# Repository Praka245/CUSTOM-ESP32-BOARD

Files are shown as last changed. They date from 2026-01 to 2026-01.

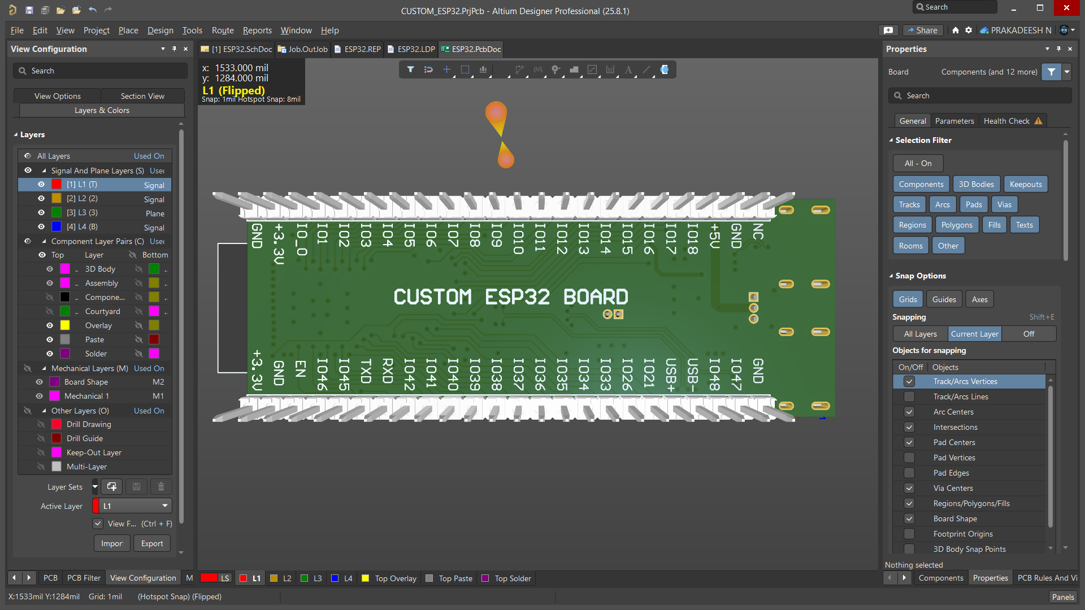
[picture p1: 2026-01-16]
IMAGES/3D VIEW/BOTTOM View.png

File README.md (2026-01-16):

# ESP32 Custom PCB Design

## 📌 Project Overview

This repository contains the complete design files for a **custom ESP32-based PCB**.  
The project focuses on schematic design, component selection, PCB layout, and manufacturing outputs such as Gerber and NC Drill files.

The design follows standard PCB design practices and is intended for **learning, prototyping, and academic purposes**.

---

## 🛠 Tools Used
Altium   

- **PCB Design Software:** Altium Designer
- **Gerber Viewer:** View Mate

---

## 🛠 Key Component and Files

- **Controller:** ESP32  
- **Output Files:** Gerber, NC Drill, BOM  
- **3D Models:** STEP (.stp)

---

## 🔍 Websites used to search Components

The following online resources were used to **search, verify, and download PCB components, footprints, symbols, and 3D models**:

1. **Digi-Key**  
2. **LCSC**
3. **Molex**  
4. **SnapEDA / SnapEDA Magic**
5. **Ultra Librarian** 
6. **3D ContentCentral**

**Note:** For 3D visualization and mechanical verification, **STEP (.stp) files** were downloaded and used.

---

## 📂 Manufacturing Output Files

This repository includes the following fabrication-ready files:

- **Gerber Files** - Copper layers, solder mask, silkscreen  
- **NC Drill Files (.DRR)** - Drill data for vias and holes  
- **Drill Reports (.TXT)** - Hole size and count information  

---

## 👁 Viewing Gerber & NC Drill Files (Optional)

To view and verify Gerber files before fabrication, the following tool was used:

### ViewMate Gerber Viewer

- Open and inspect Gerber layers  
- Verify drill alignment and hole sizes  
- Check PCB before sending to fabrication  

**LINK:** https://www.pentalogix.com/t/software-products/viewmate

---

## 🎯 Project Objectives

- Learn complete PCB design flow  
- Understand component selection and footprint verification  
- Generate fabrication-ready files  
- Practice industry-standard PCB documentation  

---

## 📐 Controlled Impedance Routing (50 Ω)

In this PCB design, **50 Ω characteristic impedance** was maintained for moderate-speed digital signal routing.

### Design Choice

- **Trace Width:** 6 mils  
- **Target Impedance:** 50 Ω  
- **Signal Type:** moderate-speed digital signals  
- **Routing Style:** Single-ended microstrip

The 6 mil trace width was selected based on the **PCB stack-up parameters**, including:
- Dielectric material (FR-4)
- Dielectric thickness between signal layer and reference plane
- Copper thickness
- Presence of a continuous ground reference plane

Using these parameters, impedance calculations confirmed that a **6 mil wide trace achieves approximately 50 Ω** characteristic impedance under the given stack-up conditions.

---

### Why 50 Ω?

- Industry-standard impedance for:
  - High-speed digital signals
  - RF and clock lines
- Minimizes:
  - Signal reflections
  - Impedance mismatch
  - EMI and signal distortion
- Ensures:
  - Signal integrity
  - Reliable data transmission

### Note

- I have calculated the Impedance using the JLPCB's Impedance Calculator based on my **Layer Stackup**

---

## 🔀 Differential Pair Routing

Differential pairs were used in this PCB design for selected high-speed signals to improve signal integrity and noise immunity.

### Why Differential Pairs?

- Transmit signals as a **pair of equal and opposite signals**
- Reduce susceptibility to:
  - External noise
  - EMI (Electromagnetic Interference)
- Improve:
  - Signal integrity
  - Timing accuracy
  - High-speed data reliability

---



---

### Design Considerations

- **Matched trace lengths** were maintained to minimize skew
- **Consistent spacing** between the differential traces was used to achieve the required **differential impedance**
- Routed over a **continuous reference plane** to ensure stable return paths

---

### Benefits

- Lower common-mode noise
- Reduced radiation and crosstalk
- Suitable for high-speed interfaces such as USB, UART (high-speed), and clock signals

Differential routing ensures robust and reliable communication in high-speed PCB designs.

---

## 📚 Custom Schematic Symbols & Footprints

For some components, **custom schematic symbols and PCB footprints** were created by carefully **referencing the manufacturer datasheets** 📄.

### 🔍 Why Custom Libraries Were Created

- Mainly for designer's convenience 😁

🛠 This approach:
- Simplifies schematic readability 🧩
- Makes routing and placement easier ✨
- Ensures correct pin mapping and package dimensions
- Reduces design errors during layout and fabrication
- Datasheets were used to verify:
  - Pin configuration
  - Pad size and spacing
  - Mechanical outline
- Both **schematic symbols** and **PCB footprints** were validated before layout

Creating custom libraries ensures **correct component placement**, **error-free assembly**, and a **professional PCB design workflow** ✅

---

## 🏭 PCB Manufacturing Considerations (JLCPCB)

The PCB design was created by **referring to JLCPCB’s manufacturing capabilities and design guidelines** to ensure smooth and error-free fabrication 🛠️.

**LINK:** https://jlcpcb.com/capabilities/pcb-capabilities

This includes:
- Trace width and spacing within JLCPCB limits
- Standard drill sizes and via dimensions
- Supported board thickness and copper weight
- Solder mask and silkscreen constraints

---

### ✅ Benefits

- High manufacturability 📈
- Reduced fabrication issues
- Faster turnaround time
- Cost-effective PCB production

Designing within JLCPCB’s capabilities ensures the PCB can be **manufactured reliably without additional modifications** 🔧

---

## SUMMARY:

This project features a custom ESP32-based PCB designed for learning and prototyping. It includes complete schematic capture, component selection, PCB layout, and fabrication-ready files (Gerber, NC Drill, BOM, and STEP). The design ensures signal integrity with controlled impedance routing, differential pair traces for high-speed signals, and is fully manufacturable according to JLCPCB guidelines.

---

### 🙋‍♂️ CONTRIBUTOR

**Prakadeesh N**  
Electronics and Communication Engineering (ECE)  
Interested in VLSI and PSB Design

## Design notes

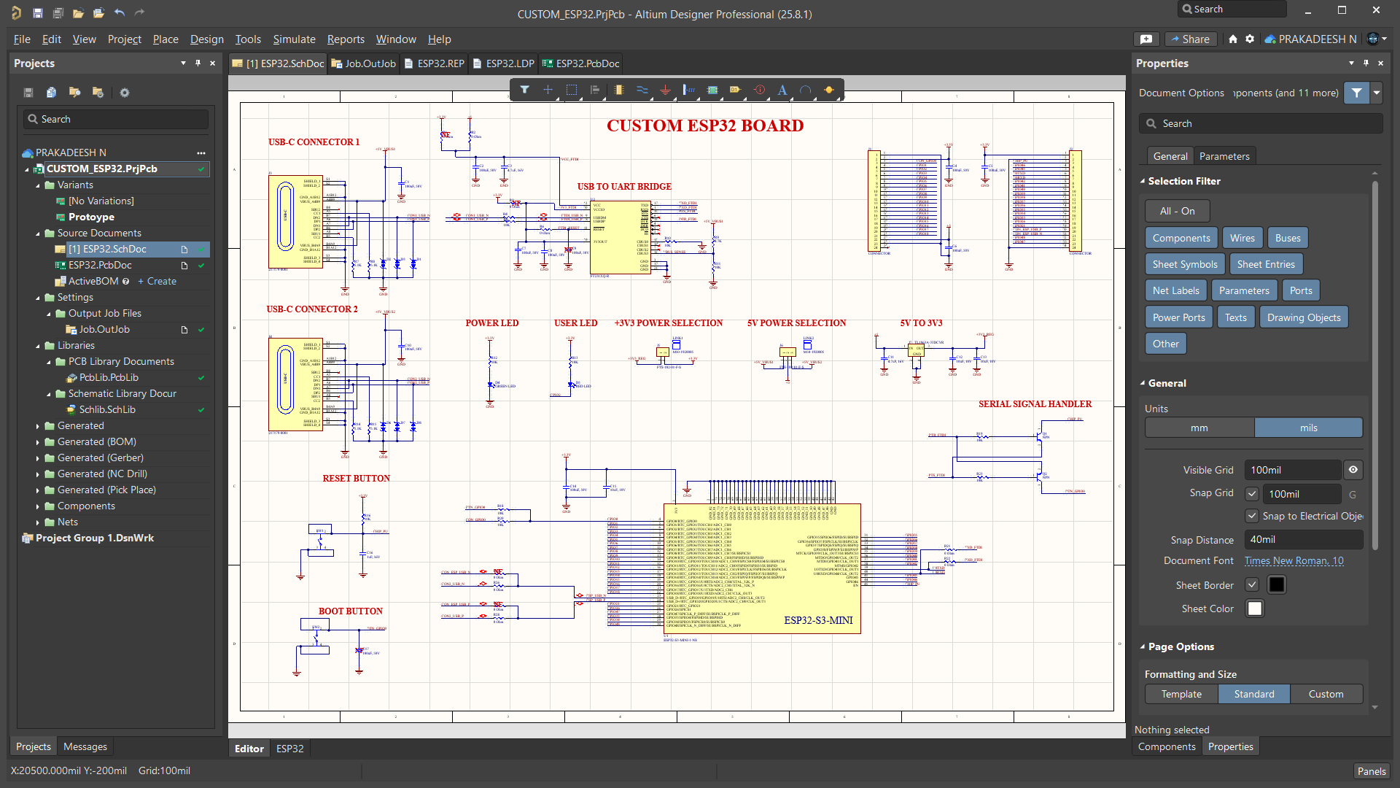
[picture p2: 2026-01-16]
IMAGES/Schematics/Schematic.png

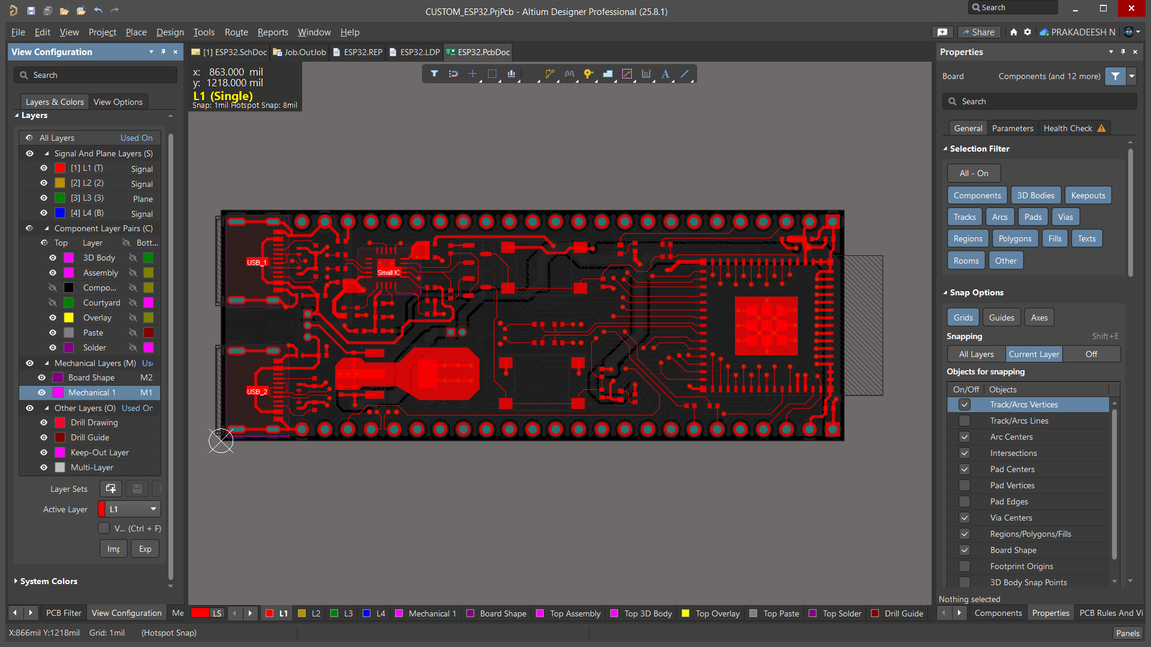
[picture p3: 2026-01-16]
IMAGES/PCB Layout/L1.png

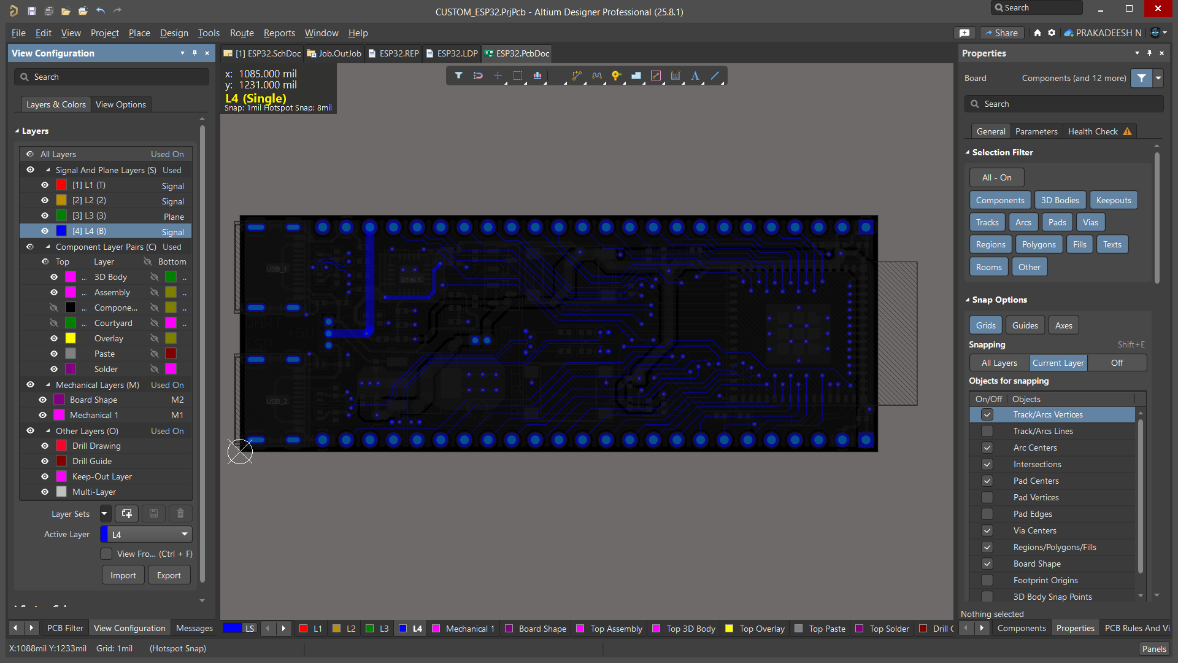
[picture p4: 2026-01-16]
IMAGES/PCB Layout/L4.png

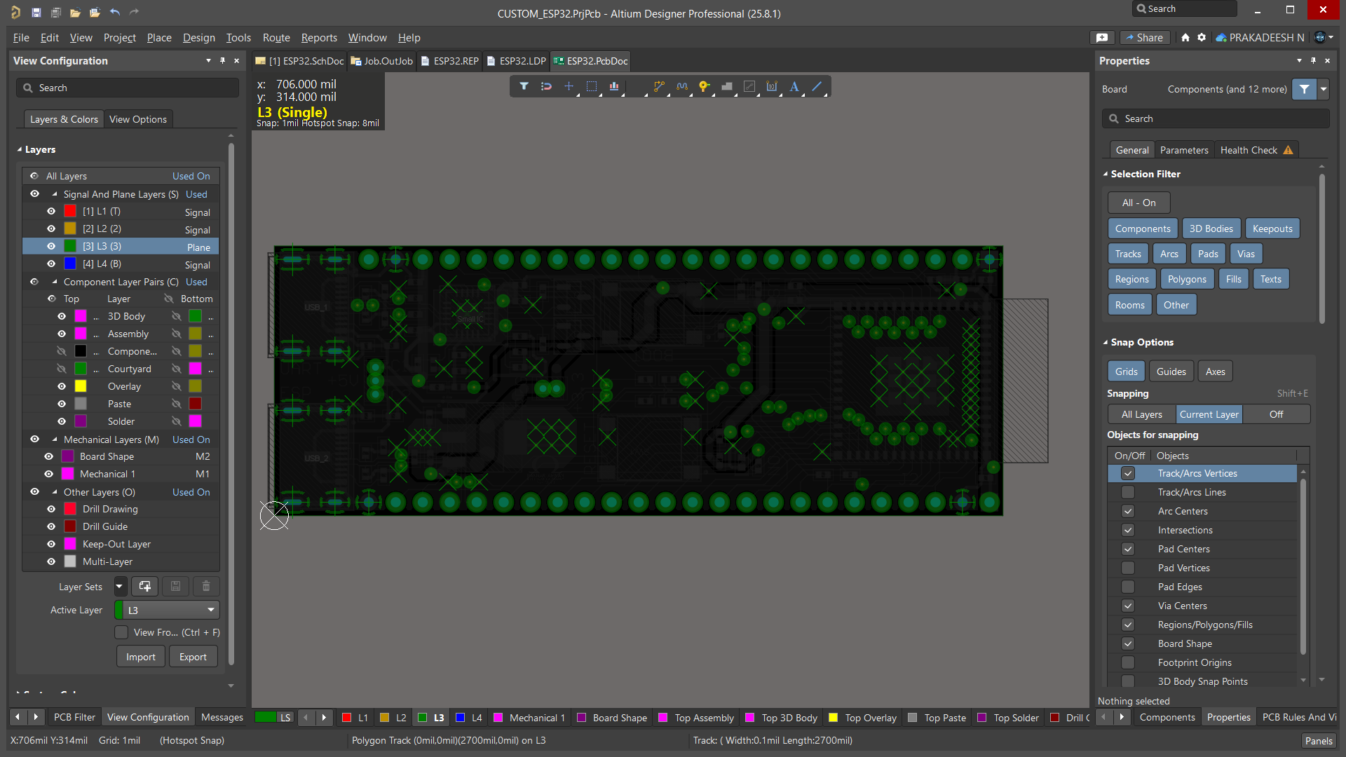
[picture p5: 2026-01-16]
IMAGES/PCB Layout/L3.png

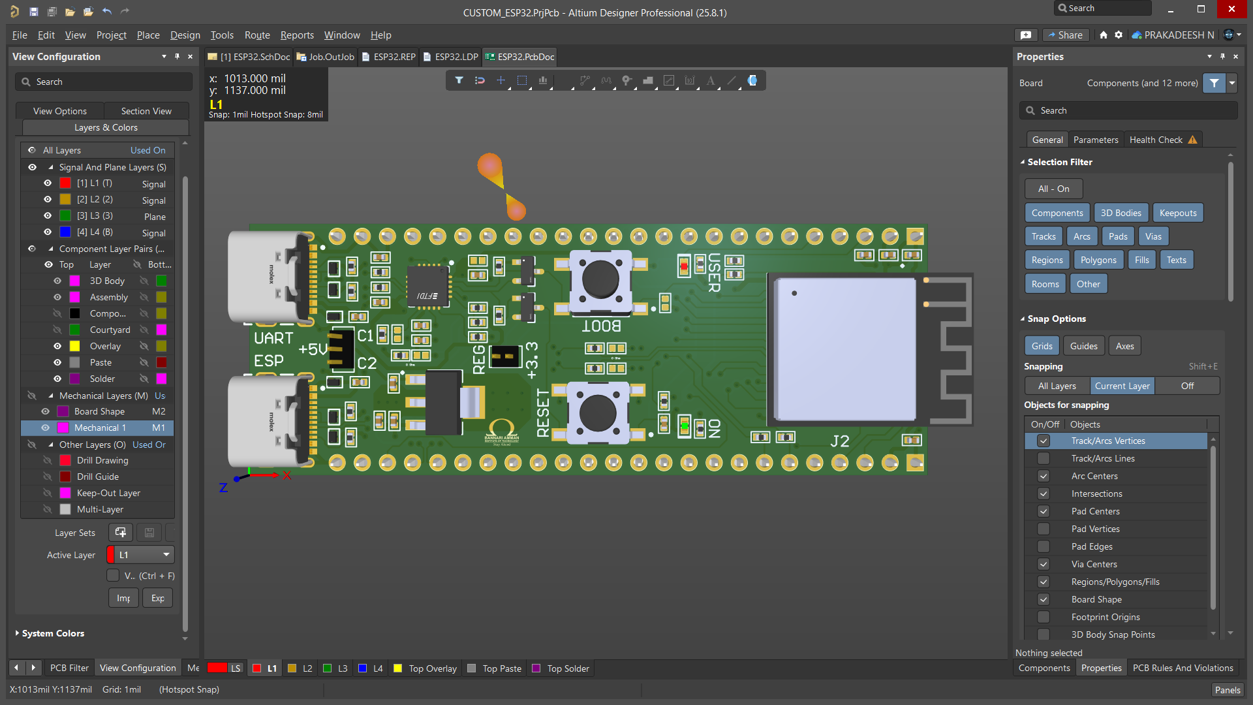
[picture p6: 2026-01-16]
IMAGES/3D VIEW/TOP View.png

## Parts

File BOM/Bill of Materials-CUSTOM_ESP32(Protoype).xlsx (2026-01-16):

Comment | Description | Designator | Footprint | LibRef | Quantity | Manufacturer | Manufacturer Part Number | Supplier | Supplier Part Number
100nF, 50V | CAP CER 0.1UF 50V X7R 0402 | C1, C2, C4, C5, C6, C7, C8, C10, C14 | CAPC1005X55N | CL05B104KB5NNNC | 9 | Samsung Electro-Mechanics | CL05B104KB5NNNC | DigiKey | 1276-CL05B104KB5NNNCCT-ND
4.7uF, 16V | CAP CER 4.7UF 16V X5R 0402 | C3, C11 | CAPC1005X55N | CL05A475MO5NUNC | 2 | Samsung Electro-Mechanics | CL05A475MO5NUNC | Avnet | CL05A475MO5NUNC
10uF, 10V | CAP CER 10UF 10V X5R 0402 | C12, C13, C15 | CAPC1005X55N | GRM155R61A106ME11D | 3 | Murata | GRM155R61A106ME11D | Arrow Electronics | GRM155R61A106ME11D
1uF, 16V | CAP CER 1UF 16V X5R 0402 | C16 | CAPC1005X55N | CL05A105KO5NNND | 1 | Samsung Electro-Mechanics | CL05A105KO5NNND | DigiKey | 1276-CL05A105KO5NNNDCT-ND
DIODE AQ3045-01ETG | TVS DIODE 5.3VWM 12VC SOD882 | D1, D2, D3, D6, D7, D8 | SOD882 | AQ3045-01ETG | 6 | Littelfuse | AQ3045-01ETG | DigiKey | F9321CT-ND
GREEN LED | LED GREEN 0402 SMD | D4 | LED_SMD_G | VLMTG1500-GS08 | 1 | Vishay | VLMTG1500-GS08 | DigiKey | 751-VLMTG1500-GS08CT-ND
RED LED | LED RED CLEAR CHIP SMD | D5 | LED_SMD_R | XZMDK68W-2 | 1 | SunLED | XZMDK68W-2 | DigiKey | 1497-1174-1-ND
CONNECTOR | Connector Header Through Hole 24 position 0.100" (2.54mm) | J1, J2 | DIP_24_PINS_2.5MM | 22-28-4245 | 2 | Molex | 22-28-4245 | DigiKey | 900-0022284245-ND
217179-0001 | CONN RCP USB2.0 TYP C 24P SMD RA | J3, J4 | FP-2171790001-MFG | 217179-0001 | 2 | Molex | 217179-0001 | Arrow Electronics | 2171790001
FTS-102-01-F-S | CONN HEADER VERT 2POS 1.27MM | J5 | HDR_2PIN_1.27 | FTS-102-01-F-S | 1 | Samtec | FTS-102-01-F-S | DigiKey | SAM15176-ND
FTS-103-01-F-S | CONN HEADER VERT 3POS 1.27MM | J6 | HDR_3PIN_1.27 | FTS-103-01-F-S | 1 | Samtec | FTS-103-01-F-S | DigiKey | 612-FTS-103-01-F-S-ND
TL1963A-33DCYR | TL1963A-33DCYR | J7 | VREG_TL1963A-33DCYR | TL1963A-33DCYR | 1 | Texas Instruments | TL1963A-33DCYR | DigiKey | 296-24897-1-ND
M50-1920005 | CONN SHUNT 1.27MM RED | LINK1, LINK2 |  | M50-1920005 | 2 | Harwin | M50-1920005 | DigiKey | 952-1727-ND
NPN | TRANS NPN 25V 1.5A SOT-23-3 | Q1, Q2 | FP-SS8050-G-IPC_B | SS8050-G | 2 | Comchip | SS8050-G | DigiKey | 641-1790-1-ND
0 Ohm | RES 0 OHM JUMPER 1/16W 0402 | R2, R6, R21, R22, R26, R28 | RESC1005X37N | RC0402JR-070RL | 6 | Yageo Group | RC0402JR-070RL | Avnet | RC0402JR-070RL
10K | RES SMD 10K OHM 1% 1/16W 0402 | R4, R5, R10, R11, R12, R13, R16, R18, R19, R20, R23 | RESC1005X37N | AF0402FR-0710KL | 11 | Yageo Group | AF0402FR-0710KL | Avnet | AF0402FR-0710KL
5.1K | RES SMD 5.1K OHM 1% 1/16W 0402 | R7, R8, R14, R15 | RESC1005X37N | AC0402FR-075K1L | 4 | Yageo Group | AC0402FR-075K1L | Avnet | AC0402FR-075K1L
4.7K | 4.7 kOhms ±5% 0.063W, 1/16W Chip Resistor 0402 (1005 Metric) Moisture Resistant Thick Film | R9 | RESC1005X37N | RC0402JR-074K7L | 1 | Yageo Group | RC0402JR-074K7L | DigiKey | 311-4.7KJRCT-ND
PushButton PTS645SH50SMTR92LFS | SWITCH TACTILE SPST-NO 0.05A 12V | SW1, SW2 | FP-PTS645SH50SMTR92LFS-MFG | PTS645SH50SMTR92LFS | 2 | C&K Components | PTS645SH50SMTR92LFS | DigiKey | CKN9085CT-ND
ESP32-S3-MINI-1-N8 | 20.5dBm ESP32-S3FN8 Chip 2.4GHz SMD WiFi Modules ROHS | U1 | XCVR_ESP32-S3-MINI-1-N8 | ESP32-S3-MINI-1-N8 | 1 | Espressif Systems | ESP32-S3-MINI-1-N8 | DigiKey | 5407-ESP32-S3-MINI-1-N8CT-ND
FT231XQ-R | IC USB SERIAL FULL UART 20QFN | U2 | FP-QFN-20-IPC_B | FT231XQ-R | 1 | FTDI | FT231XQ-R | Mouser | 895-FT231XQ-R

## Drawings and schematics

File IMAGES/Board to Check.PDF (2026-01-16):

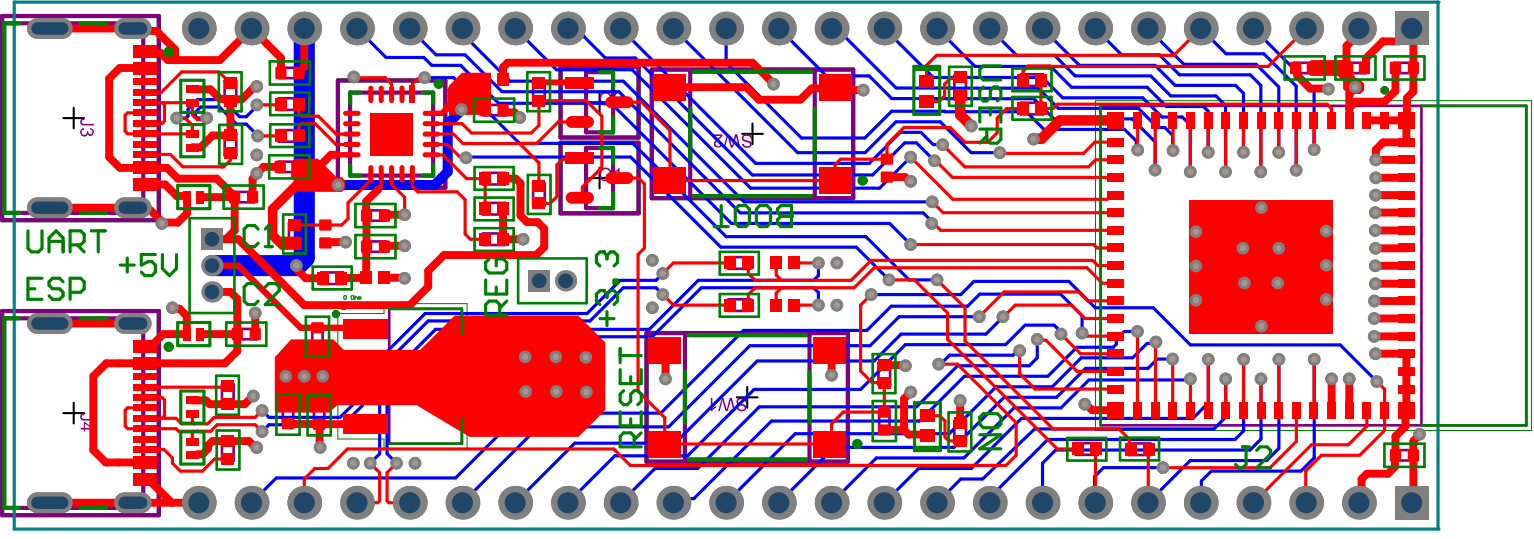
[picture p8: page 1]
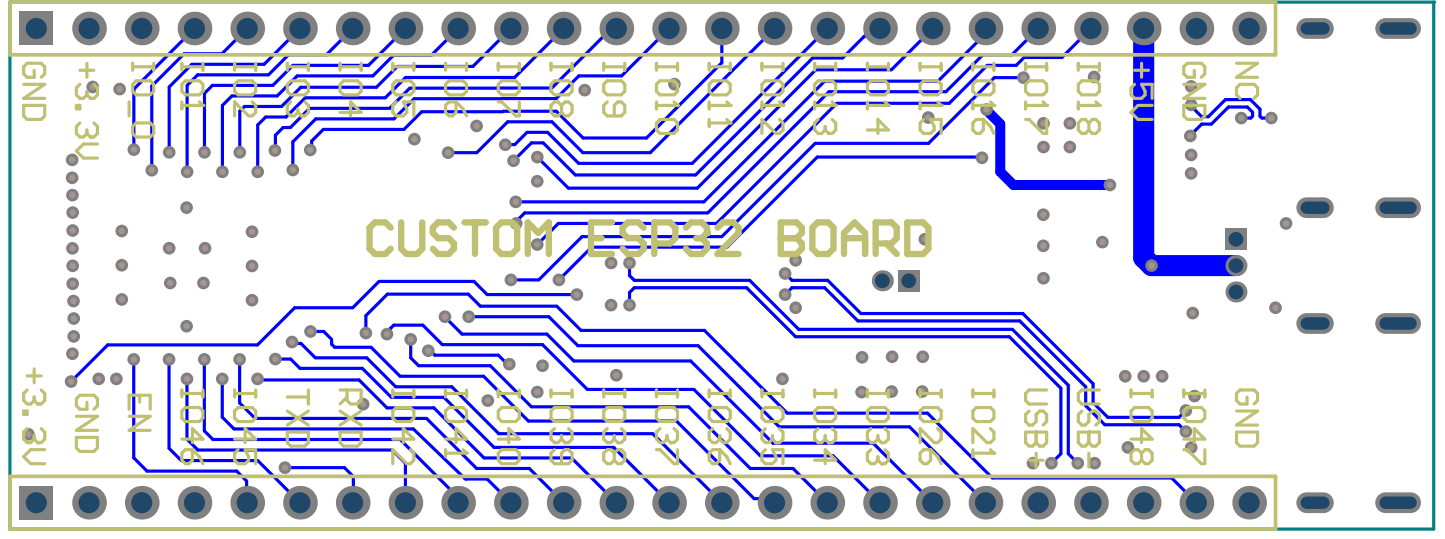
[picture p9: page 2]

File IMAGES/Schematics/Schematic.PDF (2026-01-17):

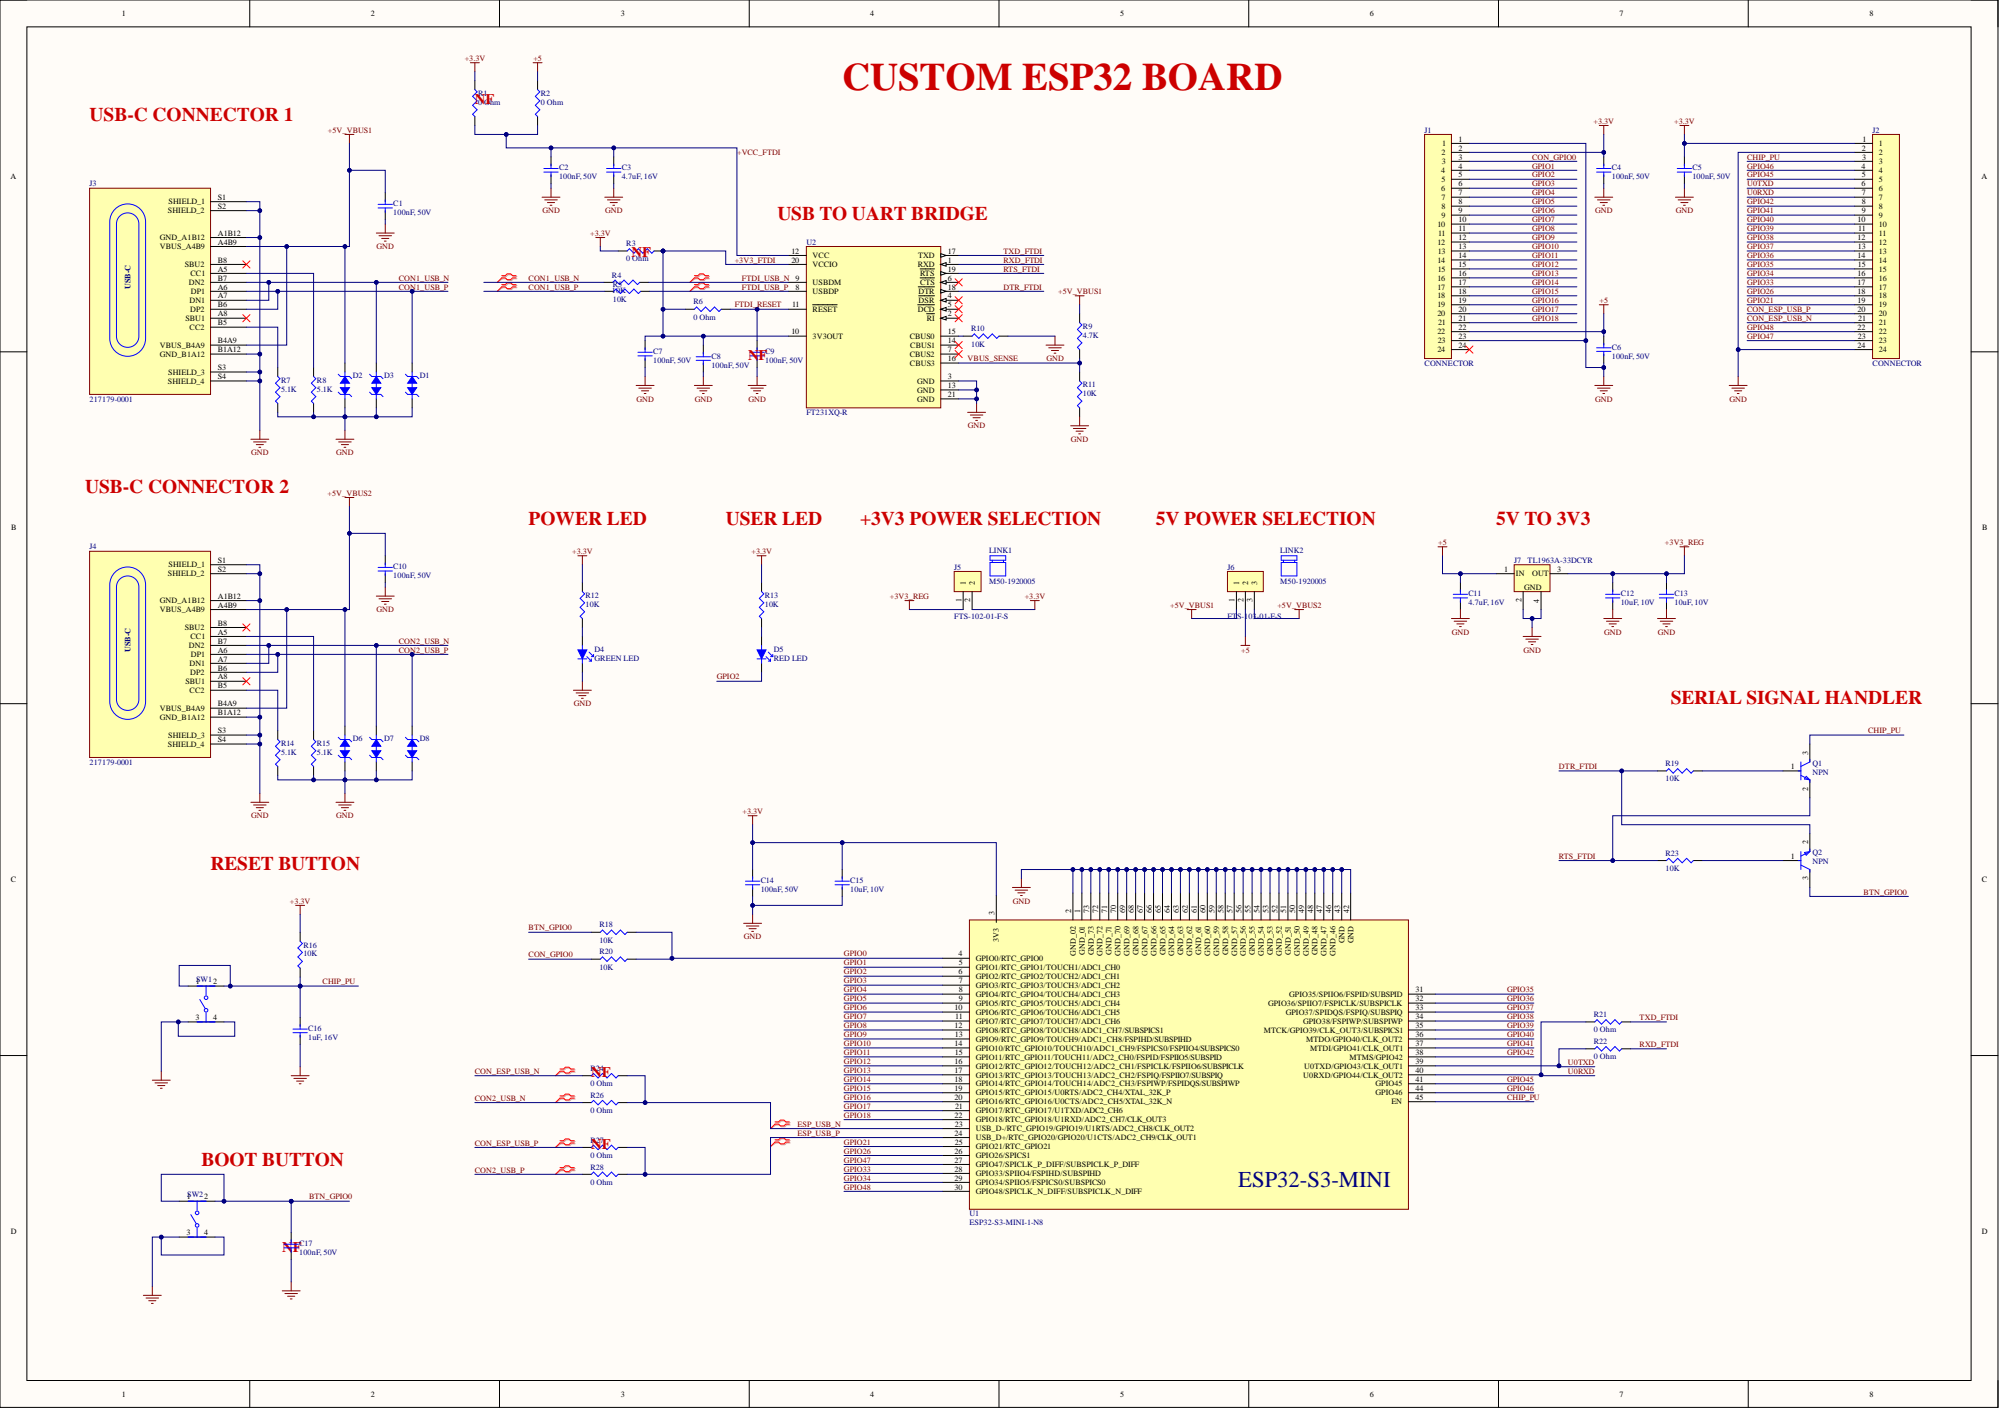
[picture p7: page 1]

1 3
2 1
